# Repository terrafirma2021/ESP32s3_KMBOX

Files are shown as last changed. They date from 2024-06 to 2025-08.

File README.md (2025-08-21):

# Project has now been merged with the MAKCU project

All code updates will now be found on my repo: [MAKCU GitHub Repository](https://github.com/terrafirma2021/MAKCM).

Names for people who are using MAKCU bins:

Top = LEFT_*.bin (DEVICE)

Bottom = RIGHT_*.bin (HOST)

# ESP32-S3 Dual Dev Kit Project

## Overview

This project utilizes two ESP32-S3 dev kits in a stacked configuration (one on top of the other) to create a versatile USB Host and Device interface. The two dev kits communicate via UART, with specific roles assigned to each:

- **ESP-B (Bottom):** Handles USB Host mode for the mouse via the left USB C connector.
- **ESP-A (Top):** Handles USB Device mode via the left USB C Connector.
- **ESP-A (Top):** replicates KMBOX B Pro commands via the right USB C connector.

## Images
Finished Design:

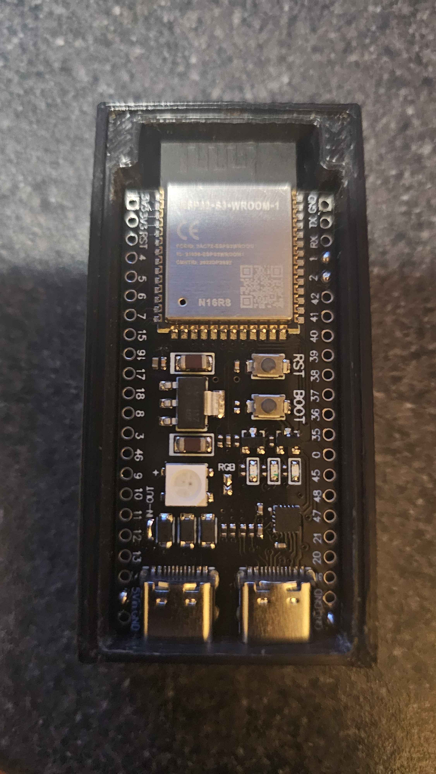
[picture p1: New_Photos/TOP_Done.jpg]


Bottom ESP Soldered pins (USB-OTG pad must be soldered!) :

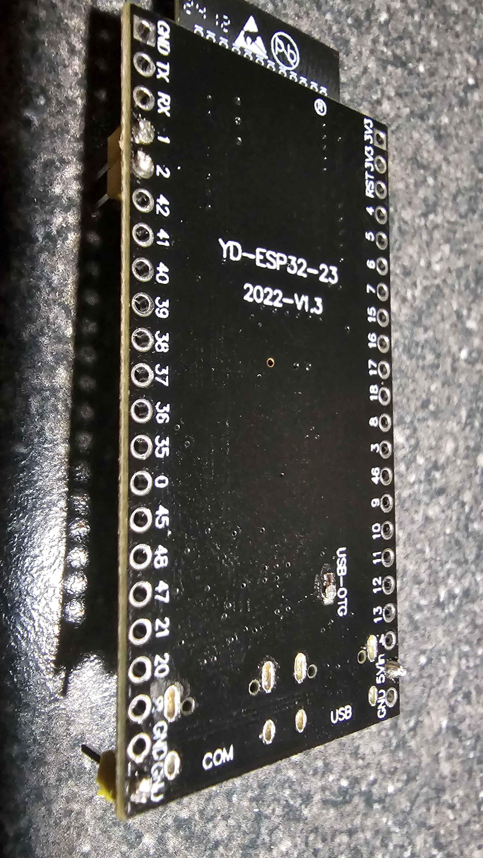
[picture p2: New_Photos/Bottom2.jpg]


Top ESP Soldered pins:

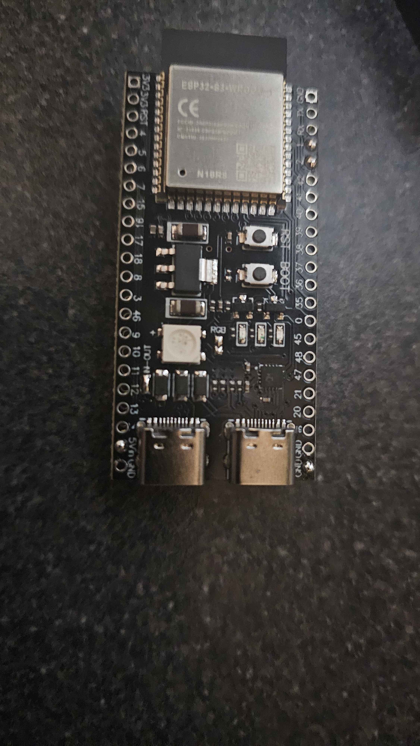
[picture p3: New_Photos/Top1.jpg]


Side view of soldered pins:

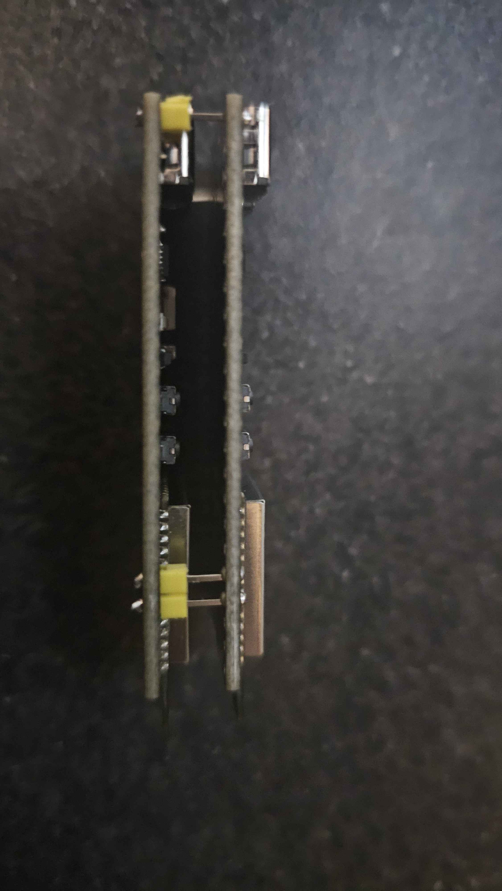
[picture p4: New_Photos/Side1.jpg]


## Boards Used

- **YD-ESP32-S3 N16R8**
  - [Amazon](https://www.amazon.co.uk/dp/B0CQNBJSCP)
  - NOTE: *** Please ensure you buy a N16R8 board, i will create a boards.json for you if not, but it will save your time if you get the right device, 

## Additional Requirements

- Soldering is required to link the 5V pads (next to the RGB smd) to pass 5V out of the 5V pin on the bottom ESP.
- The USB_OTG pads under the board need to be soldered to enable OTG host mode on the bottom ESP.
- 3D Printer for the case, Its very tight :) (STL Included), printed on k1max with 0.6 bontech CHT 0 issues.

## Connectivity

- A USB-C OTG cable is required to connect a mouse to the ESP.
- Standard USB-C to male USB cables are suitable for COM/USB Device mode.

## Communication Setup

The two ESP32-S3 dev kits communicate using UART, allowing seamless data transfer between them.

## Functionality

- **USB Host Mode (ESP-B):** This dev kit acts as a USB host for the mouse, managing data and sending commands to the other dev kit.
- **USB Device Mode (ESP-A):** This dev kit handles device mode operations and replicates KMBOX B Pro commands through its right USB C connector.

## Files Included

- Both Devkit board code
- 3D Printed case
- Python script to test the project

## Summary

The transition to version 2 of the project has brought significant improvements in efficiency and performance. By utilizing DMA and ISRs for serial communication, the system now handles commands much faster, with average command processing times reduced to under 700 microseconds. These updates have enhanced the overall responsiveness and stability of the project, making it a more robust solution for USB Host and Device interfacing.

## PCB Pinout

Since this is a stacked configuration, all marked pins will be connected directly to both ESP modules. The grounds are shared, so the additional ground connections only enhance board support. Avoid using the 3.3V pin, as we will power the devices via the LDOs.

The use of the IN/OUT pad on the top will provide power to the bottom ESP, ensuring that both ESP modules power up simultaneously when using the top ESP.

Note: This power flow is -Not Unidirectional-! its direction of VCC is : Top ---> Bottom.
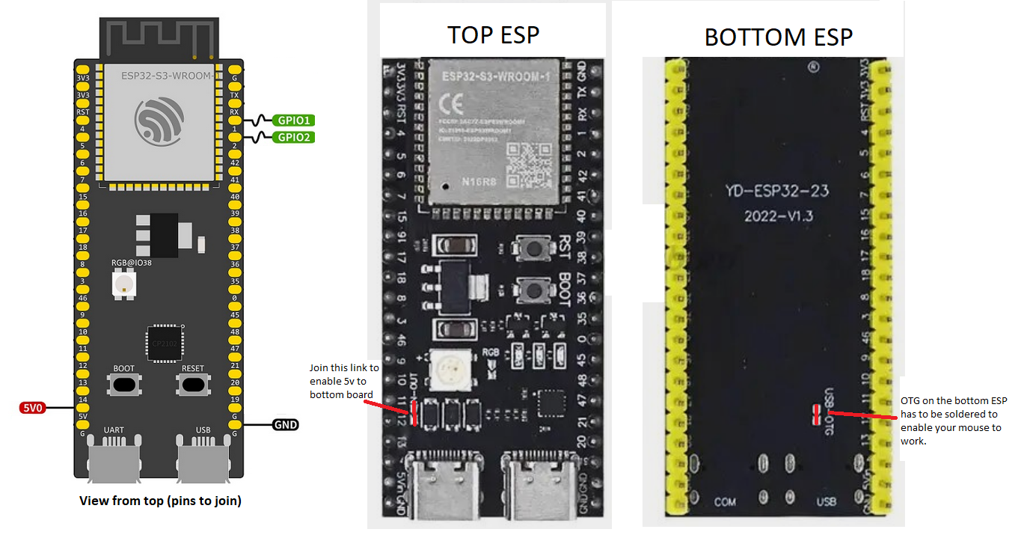
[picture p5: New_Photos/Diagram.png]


## Cut traces on board!

Be aware if you do not cut the traces on the board, the top devkit will reset every time you open the com port .....

Note: you will have to then flash the top devkit from the left usb port (hold boot button and then connect usb cable to left side) !This is only for the top esp.
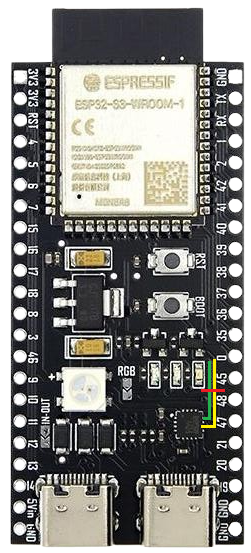
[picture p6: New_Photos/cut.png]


## Thanks:
- [thecloneop](https://discord.gg/UqzcRTVpky): Bug tester
- Many more, will add you all when i get onto the list;

## NOTE: 
- You will need 1 x USB-C OTG cable, (the adaptors are too wide and will block the other port!)
- 2x USB-C to A cables
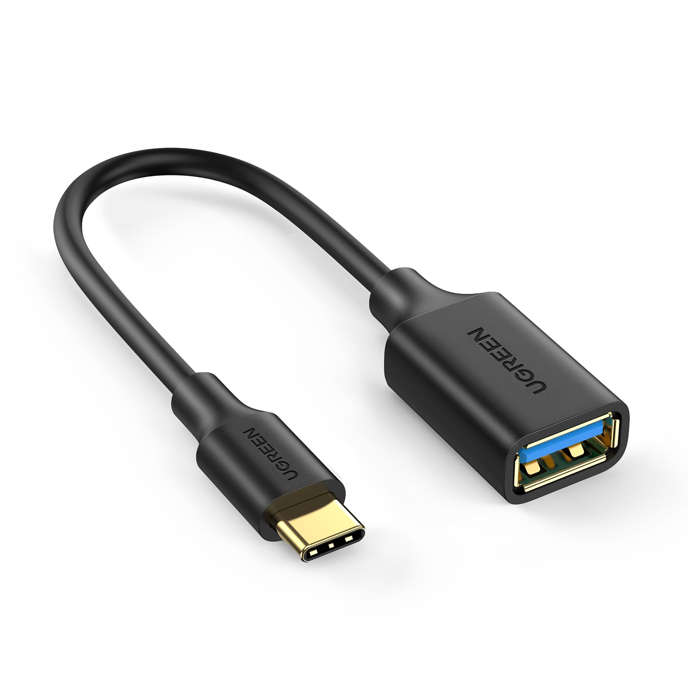
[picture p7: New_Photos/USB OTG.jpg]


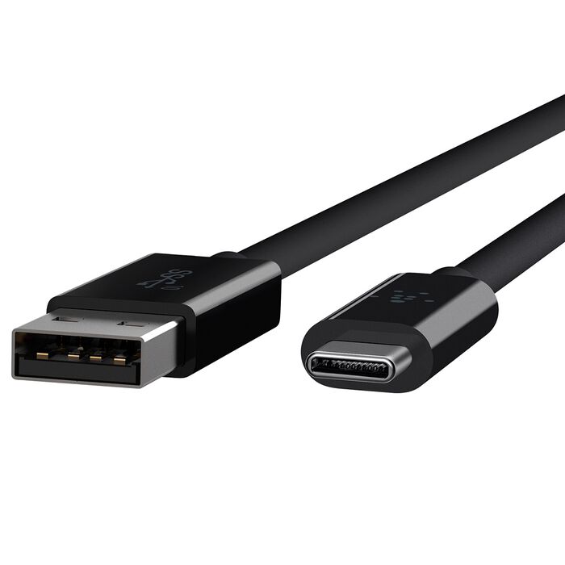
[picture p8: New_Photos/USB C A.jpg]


## Users Builds

Community submissions and custom builds by other makers!

<strong>Photo credit:</strong> wod<br>
<strong>Discord user ID:</strong> energetic_papaya_53264



<strong>Photo credit:</strong> 清欢科技工作室<br>
<strong>Discord user ID:</strong> lesliecheung

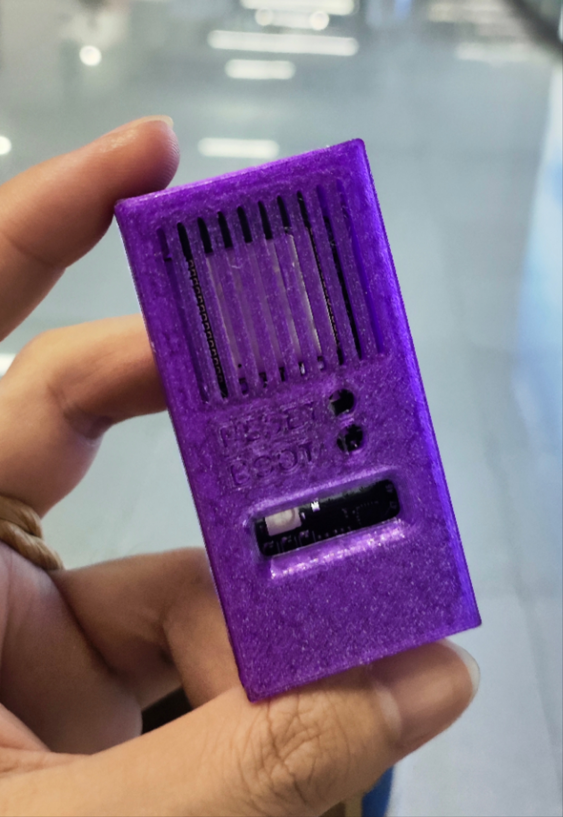
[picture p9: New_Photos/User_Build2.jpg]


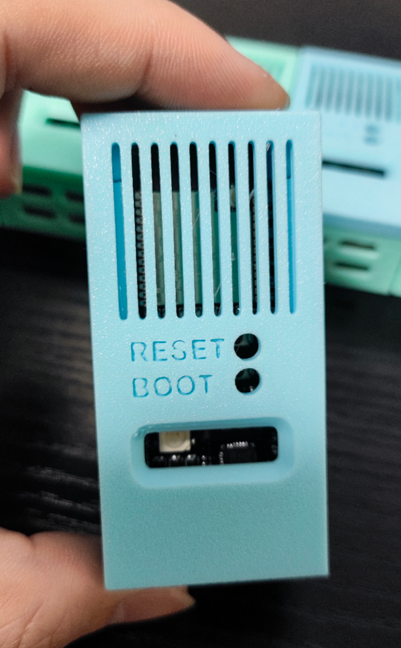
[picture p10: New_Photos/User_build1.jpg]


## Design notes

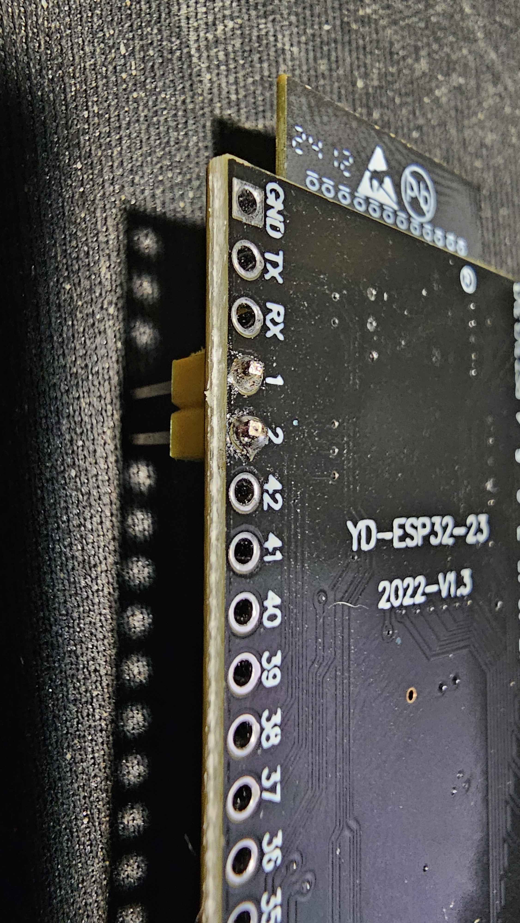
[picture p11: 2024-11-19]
New_Photos/Bottom3.jpg

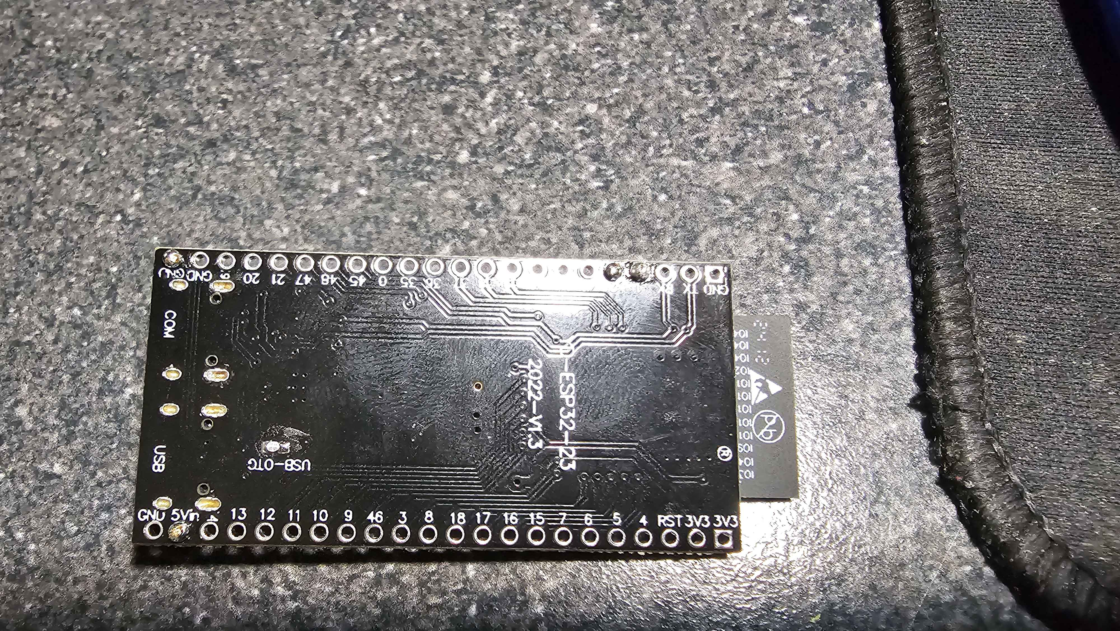
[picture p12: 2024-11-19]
New_Photos/Bottom_OTG.jpg

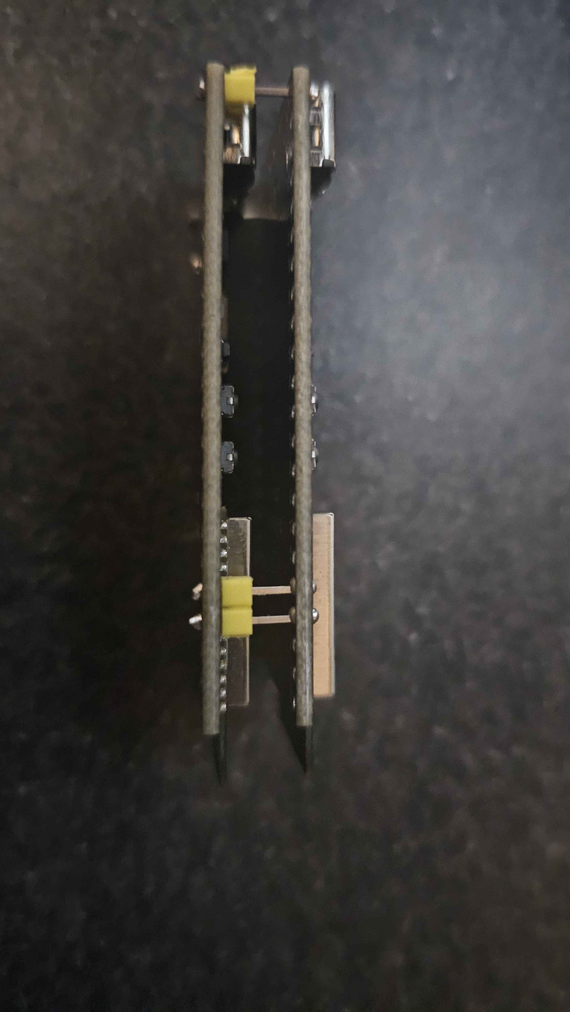
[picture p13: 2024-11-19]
New_Photos/Side2.jpg

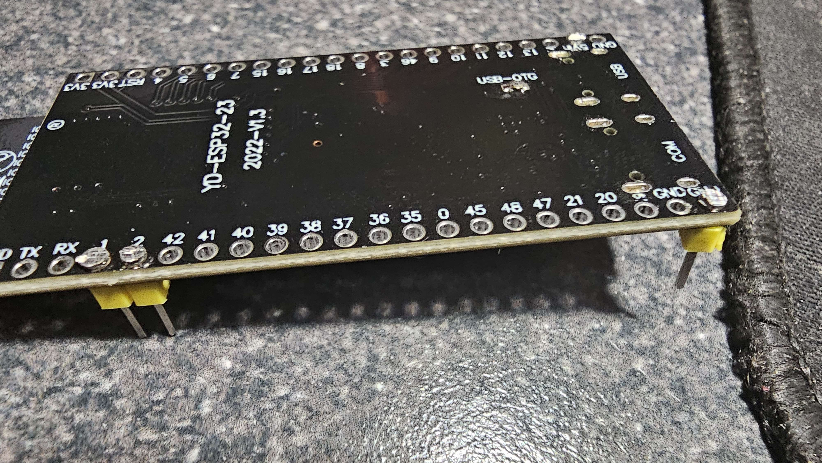
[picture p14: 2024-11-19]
New_Photos/Bottom1.jpg

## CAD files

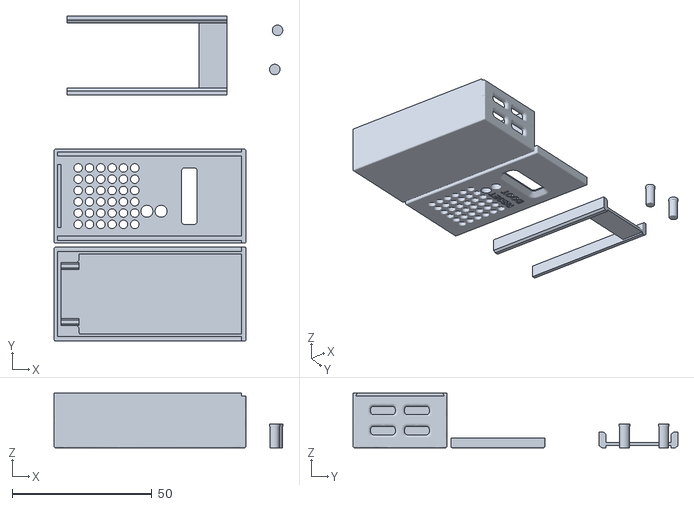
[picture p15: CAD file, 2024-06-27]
3D-Print/esp32 dual mcu case.stl
81.8 x 116.2 x 19.5

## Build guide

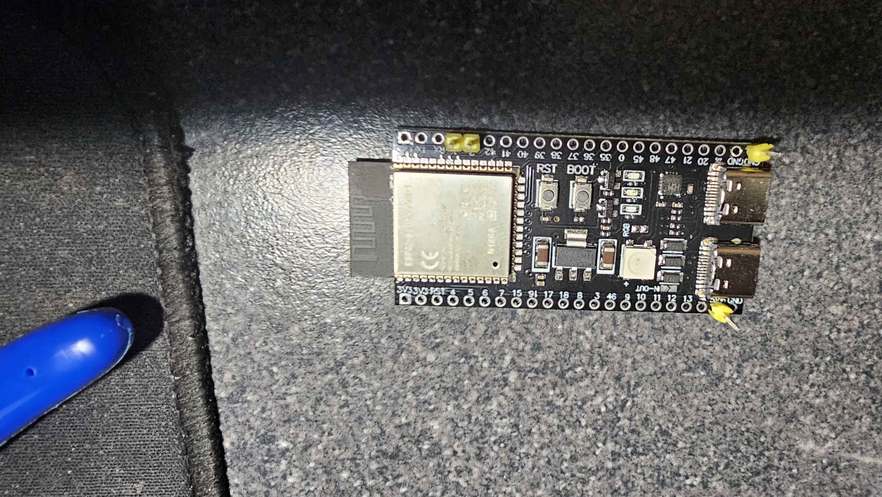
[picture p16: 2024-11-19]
New_Photos/Bottom_soldered.jpg

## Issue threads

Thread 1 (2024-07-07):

Pinouts

F0RSV1NNA, 2024-07-07:
Would love to see a pinout, or a photo of both sides for soldering!
 amazing project going to test it out once my dev boards arrive.

F0RSV1NNA, 2024-07-07:
also, should i be soldering the boards together before flashing or after flashing & which ports do i use to flash?
i know these probably seem like dumb questions but would be very helpful as a beginner in platformIO

terrafirma2021, 2024-07-08:
HI, Thanks for taking the time to try my project!
Sorry for not attaching the PCB design and pinouts!

I have updated my readme now, if you need any advice be sure to let me know.

Good luck with your project :)

terrafirma2021, 2024-07-08:
Regarding soldering vs flashing, I would advise to just flash a standard hello world CPP to your boards, just to ensure that they do function first.

But once you are happy then sure solder away then you can flash again without issues, having the pins connected before the code in this case is not a problem :).

Cheers

terrafirma2021, 2024-07-08:
https://github.com/terrafirma2021/ESP32s3_KMBOX/blob/main/Photos/pcb_design.png

Designs added and updated, thanks!

F0RSV1NNA, 2024-07-11:
> https://github.com/terrafirma2021/ESP32s3_KMBOX/blob/main/Photos/pcb_design.png
>
> Designs added and updated, thanks!

https://github.com/terrafirma2021/ESP32s3_KMBOX/assets/137400069/c34ac423-2fa3-49a3-8681-16719b8afe11

Accidentality ordered n8r2's but my n16r8's came in today! and i've got it working without an issue!! Amazing project which im learning alot about esp32s because of. thank you for this amazing project absolutely sniffing around your other projects now for my MT-10 when im feeling more confident.

Closed 2024-07-08.

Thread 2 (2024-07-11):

Usb C to Usb A adapter

TheCloneOp, 2024-07-11:
I built the board and flashed the firmware onto it and tested it using wasd and it moved my mouse but I cant get any power to go my mouse for me to try and move my mouse while the device is plugged in

terrafirma2021, 2024-07-11:
Hi, can you enable
build_flags = -DCORE_DEBUG_LEVEL=5
on your bottom esp and submit a debug for me please

TheCloneOp, 2024-07-11:
I'm very new to visual code when do I go to enable that

terrafirma2021, 2024-07-11:
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
it is here sir

TheCloneOp, 2024-07-11:
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
like so?

terrafirma2021, 2024-07-11:
yes sir then build and send a debug log please

TheCloneOp, 2024-07-11:
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
Sorry just want to make sure first day ever using this. Do I click this

terrafirma2021, 2024-07-11:
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

TheCloneOp, 2024-07-11:
ok I did that how do I send a debug log now?

terrafirma2021, 2024-07-11:
yes please

the debug is handled via serial

TheCloneOp, 2024-07-11:
I suppose I should rephrase what do I need to go to and click to that and if discord would be easier I can screen share, Im a complete noob

terrafirma2021, 2024-07-11:
https://github.com/terrafirma2021/ESP32s3_KMBOX/blob/main/Test_Script/logger.py

Here I added my serial tool for you to upload the log file, keep all chat to my repo because it will help others, thus its important to assist others who may have the same issue

Run the py in a folder and it will create a log file for you,
then just append the log here.

make sure that your baud rate matches

Serial0.begin(230400);

TheCloneOp, 2024-07-11:
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
like so and press 1?

terrafirma2021, 2024-07-11:
You don't need to run it from vscode

just run the py by double clicking, it will handle the log for you, you will have the txt file in the same folder as the py

terrafirma2021, 2024-07-11:
the txt file will be created if it does not exist, and it will append to the txt file if it does :)

TheCloneOp, 2024-07-11:
[log.txt](https://github.com/user-attachments/files/16171519/log.txt)

TheCloneOp, 2024-07-11:
I think I did it right

terrafirma2021, 2024-07-11:
yes, now plug in the mouse and remove to see if the callback triggers whilst the serial is connected

TheCloneOp, 2024-07-11:
I plugged mouse in and it didnt work not following you on this "see if the callback triggers whilst the serial is connected" my discord is thecloneop could you add me so I can screen share for you bc I think I did it wrong

terrafirma2021, 2024-07-11:
sure

terrafirma2021, 2024-07-12:
Thanks for the time to help with my code, the issue ended up being a bad board,

Referenced here also:
<a href="https://github.com/espressif/esp-idf/issues/11456">GitHub Issue #11456</a>

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

Closing issue.

Closed 2024-07-12.

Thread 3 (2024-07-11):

Strange Power Behavior

F0RSV1NNA, 2024-07-11:
Noticed this just now after getting mine fully soldered and working earlier today.

it appears on my logitech g502x (USB-C to USB-C) and G pro wireless (micro-b to USB-C adapter) mouses

while plugged in they have no on board DPI control like they typically would even when "disconnected" from a PC.

as-well the battery's both drained INSANELY fast.
which is weird since they are hardwired straight from the esp32 device and would be provided power to "charge"/run off
they will both eventually drain the battery fully (an hour maybe longer) and turn off completely as if unplugged.

Just theorizing but maybe something to do with configurationDescriptor_MaxPower if the mouse is also reading that some how? and thinking its fully charged or wrong value so = no charge request.

 just got it up and running a few hours ago going to attempt tweaking with it later but its bed time for right now while the mice recharge
 and will actually try changing the hardcoded values in USBSetup.h to match one of my mice once i learn how to dump it FULLY.

Also thanks again for this amazing project, and the support your giving to those who are inexperienced.

terrafirma2021, 2024-07-11:
HI, thanks for the feedback. The way USB works is the host will poll the mouse, and the mouse will tell the host if we have data to handle or not, my approach did not take into account the needs of battery saving on the wireless mouse. So it will be polling your mouse at 1000hz until the battery dies, It's simple to solve using a reduced poll rate and when the mouse responds with data it will wake up to max poll rate until some idle time and the sleep will kick in. I will look how windows handles the timing for this and include this method for you.

terrafirma2021, 2024-07-13:
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
I have updated and enabled remote wakeup for you, i will push another update soon

terrafirma2021, 2024-07-13:
Closing the issue as i have produced a fix, If there is any issue, let me know. Thanks

Closed 2024-07-13.

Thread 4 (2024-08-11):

Flashing board

Shocka-Zulu, 2024-08-11:
Good afternoon, firs time with an esp32 board, I've got vs-code and the ide setup build runs fine but i get a chip stops responding error when attempting to flash

Auto-detected: COM21
Uploading .pio\build\esp32-s3-n16r8\firmware.bin
esptool.py v4.5.1
Serial port COM21
Connecting.....
Chip is ESP32-S3 (revision v0.2)
Features: WiFi, BLE
Crystal is 40MHz
MAC: 3c:84:27:ca:7e:dc
Uploading stub...
Running stub...
Stub running...
Changing baud rate to 921600
Changed.
Configuring flash size...

Traceback (most recent call last):
  File "\.platformio\packages\tool-esptoolpy\esptool\__init__.py", line 1032, in _main
    main()
  File "\.platformio\packages\tool-esptoolpy\esptool\__init__.py", line 816, in main
    esp.flash_set_parameters(flash_size_bytes(args.flash_size))
  File "\.platformio\packages\tool-esptoolpy\esptool\loader.py", line 1184, in flash_set_parameters
    self.check_command(
  File "\.platformio\packages\tool-esptoolpy\esptool\loader.py", line 435, in check_command
    val, data = self.command(op, data, chk, timeout=timeout)
                ^^^^^^^^^^^^^^^^^^^^^^^^^^^^^^^^^^^^^^^^^^^^
  File "\.platformio\packages\tool-esptoolpy\esptool\loader.py", line 404, in command
    p = self.read()
        ^^^^^^^^^^^
  File "\.platformio\packages\tool-esptoolpy\esptool\loader.py", line 337, in read
    return next(self._slip_reader)
           ^^^^^^^^^^^^^^^^^^^^^^^
StopIteration

A fatal error occurred: The chip stopped responding.
*** [upload] Error 2

any guidance would be appreciated

terrafirma2021, 2024-08-26:
HI sorry for getting back to you late,

the issue is your psram config on your board.

Please check the specs of your dev kit,

my code was designed for the n16 r8 variant of the dev kit and you may need to make changes,

its reported by the
esp.flash_set_parameters(flash_size_bytes(args.flash_size))

If you use the esptool.py flash_id

it will tell you,

you can then make changes to the board to match

good luck with your project

terrafirma2021, 2024-08-26:
Closing this issue now with your fix, if you get stuck further then please feel free to reopen .

cheers

Closed 2024-08-26.

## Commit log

2024-07-08 Rename PCB Design.png to PCB_Design.png
2025-08-21 Added traces to cut
